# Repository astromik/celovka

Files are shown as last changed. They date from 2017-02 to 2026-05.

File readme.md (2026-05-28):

# Astronomická èelovka s ATtiny25

Praktická èelovka urèená pøedevším pro astronomické pozorování. Obsahuje dvì sady LED (èervenou a bílou) s plynule nastavitelnou intenzitou a extrémnì nízkou spotøebou v režimu spánku.

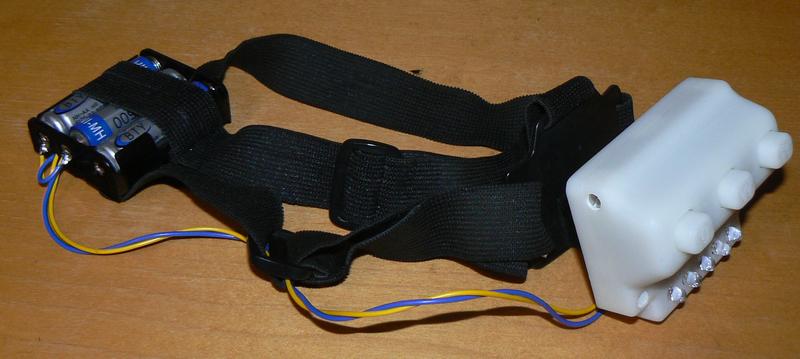
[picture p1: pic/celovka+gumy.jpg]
obrazek celovky vcetne baterii a gum


## Hlavní funkce

- Dvì barvy svìtla (èervená + bílá) s 10 úrovnìmi jasu (logaritmická regulace)
- Režim SLEEP s odbìrem pod 1 µA
- Automatické uspání po 10 minutách neaktivity
- Indikace stavu baterie (1–4 bliknutí)
- Kompaktní a spolehlivé ovládání tøemi tlaèítky

## Ovládání

### Tlaèítko 1 – RED
- **Krátký stisk** (pøi zhasnuto): rozsvítí èervenou sadu LED
- **Krátký stisk** (pøi svícení èervené): zhasne èervenou sadu
- **Dlouhý stisk** (> 1 s): rozsvítí èervenou, ale po uvolnìní tlaèítka se automaticky zhasne
- V režimu nastavení jasu: **zvyšuje jas**

### Tlaèítko 2 – WHITE
- **Dlouhý stisk** (~0,7 s): rozsvítí bílou sadu LED (ochrana proti náhodnému zapnutí)
- Pokud bílá sada LED svítí, stisk tlaèítka WHITE ji zhasne
- V režimu nastavení jasu: **snižuje jas**

### Tlaèítko 3 – OFF
- **Krátký stisk**: zhasne právì svítící LED
- **Držení + RED nebo WHITE** (pøi svícení): vstup do režimu nastavení jasu
- **Dlouhý stisk** (2 s) pøi zhasnutých LED: pøechod do režimu **SLEEP** (nebo probuzení)

### Nastavení jasu
1. Rozsvi�te požadovanou sadu LED
2. Stisknìte a držte tlaèítko **OFF**
3. Tlaèítkem **RED** zvyšujete jas, tlaèítkem **WHITE** snižujete jas (10 krokù)
4. Uvolnìním tlaèítka **OFF** nastavení ukonèíte (LED zùstane svítit)

### Režim SLEEP
- Pøi zhasnutých LED stisknìte tlaèítko **OFF** na ~2 sekundy › 2× blikne èervená LED
- Tlaèítka RED a WHITE se zablokují
- Odbìr klesne **pod 1 µA**

**Probuzení:** Podržte tlaèítko **OFF** na ~2 sekundy › 1× blikne èervená LED.

### Autosleep
Pokud je èelovka déle než ~10 minut neaktivní (LED zhasnuté), automaticky pøejde do režimu SLEEP.

### Test stavu baterie
Pøi zhasnutých LED stisknìte nejprve tlaèítko **WHITE** a do 0,7 sekundy k nìmu pøidejte tlaèítko **RED**.

- Èelovka zaène blikat poslednì použitou barvou
- Poèet bliknutí udává stav baterie:
  - **4×** = baterie dobrá / plná
  - **3×** = stav OK
  - **2×** = baterie slabá
  - **1×** = baterie vybitá (doporuèuji vymìnit)
- Blikání ukonèíte stiskem tlaèítka **OFF**

## Technické informace

**Procesor:** ATtiny25 (8 MHz)  
**Napájení:** 3× AA (1,5V alkalické nebo 1,2V NiMH)  
**Low Fuse:** `0xE2`  
**High Fuse:** `0xD7`  
**Velikost programu:** ~1868 bajtù (91 % FLASH)

**Spotøeba:**
- Zhasnuto (aktivní režim): 4–7 mA
- SLEEP režim: < 1 µA

## Schéma zapojení

*[schéma](https://github.com/astromik/celovka/blob/master/schema/celovka-schema.gif)*

## Kompilace a nahrání

Použijte Arduino IDE + podporu pro ATtiny.  
Doporuèené nastavení:
- Board: ATtiny25/45/85
- Clock: 8 MHz (internal)
- Burn Bootloader (pro správné nastavení fuse bitù)

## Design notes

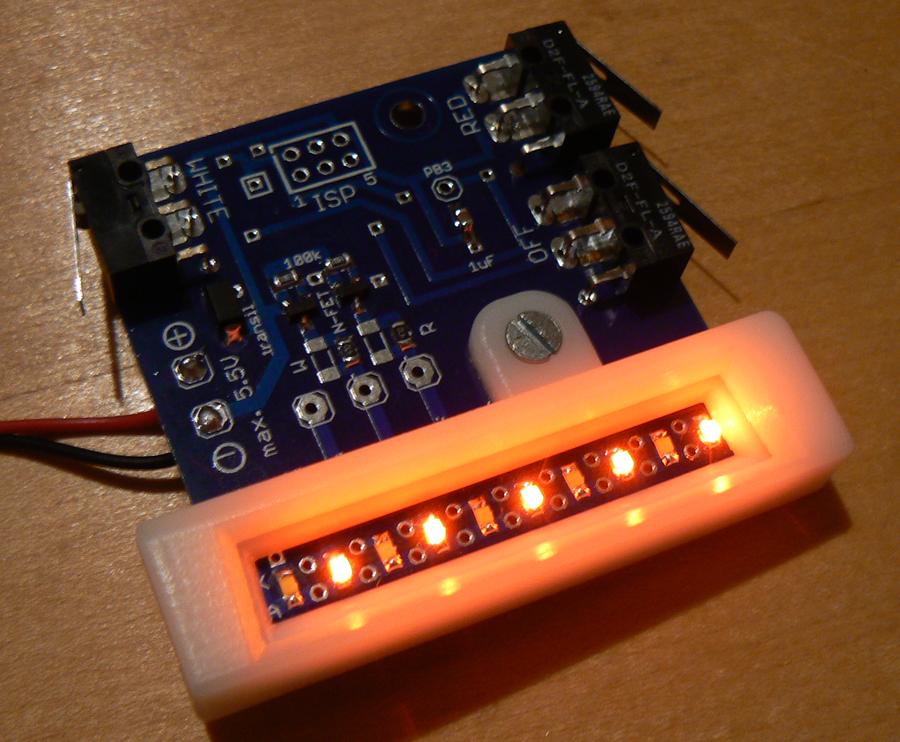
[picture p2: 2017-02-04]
pic/ledshield+pcb1.jpg

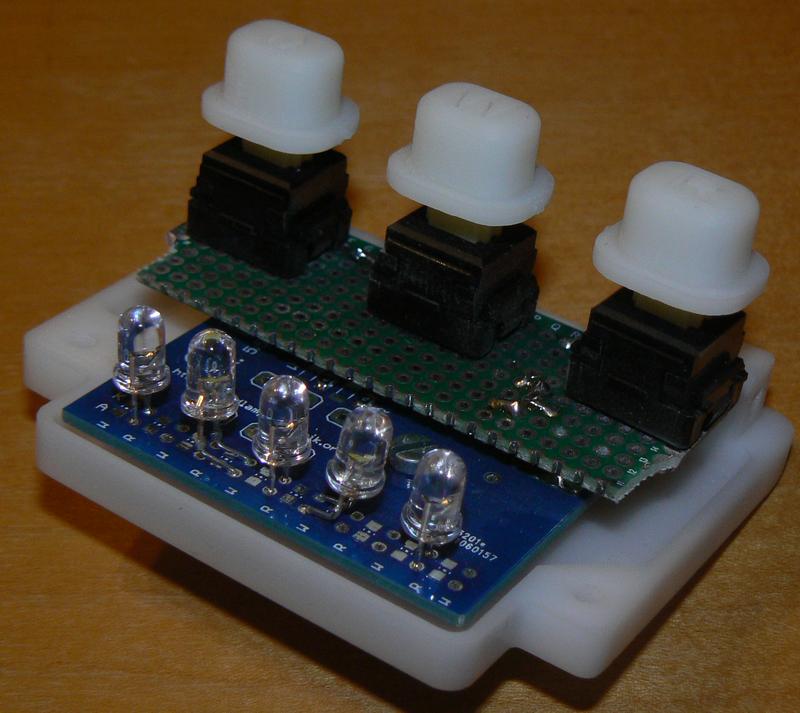
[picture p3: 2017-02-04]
pic/hmatniky.jpg

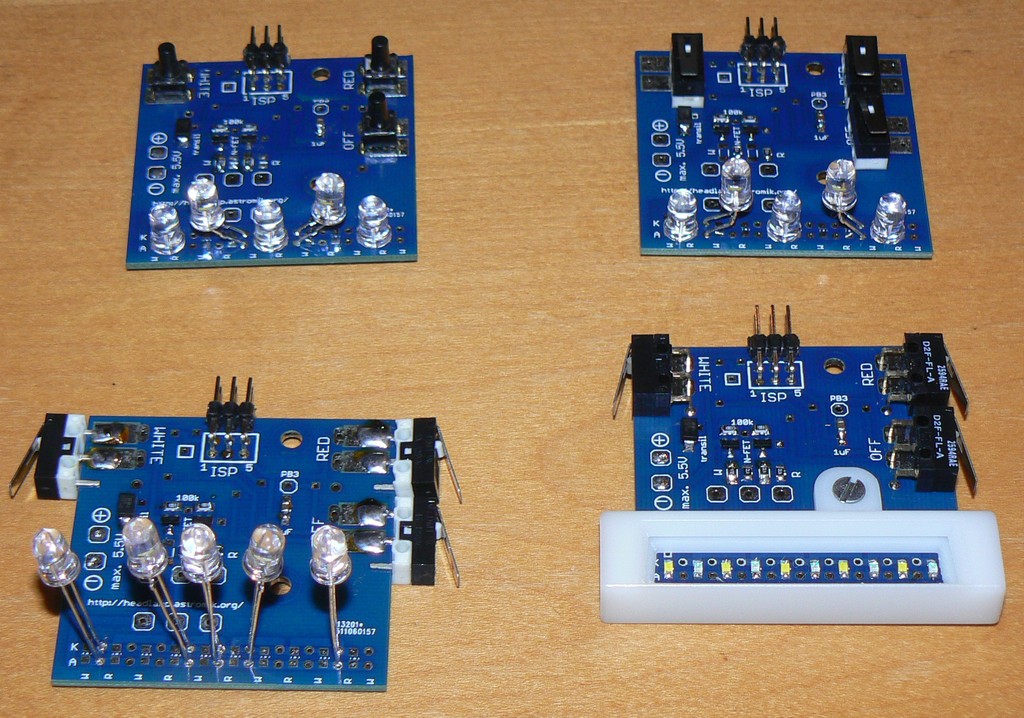
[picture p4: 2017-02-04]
pic/fotka1.jpg

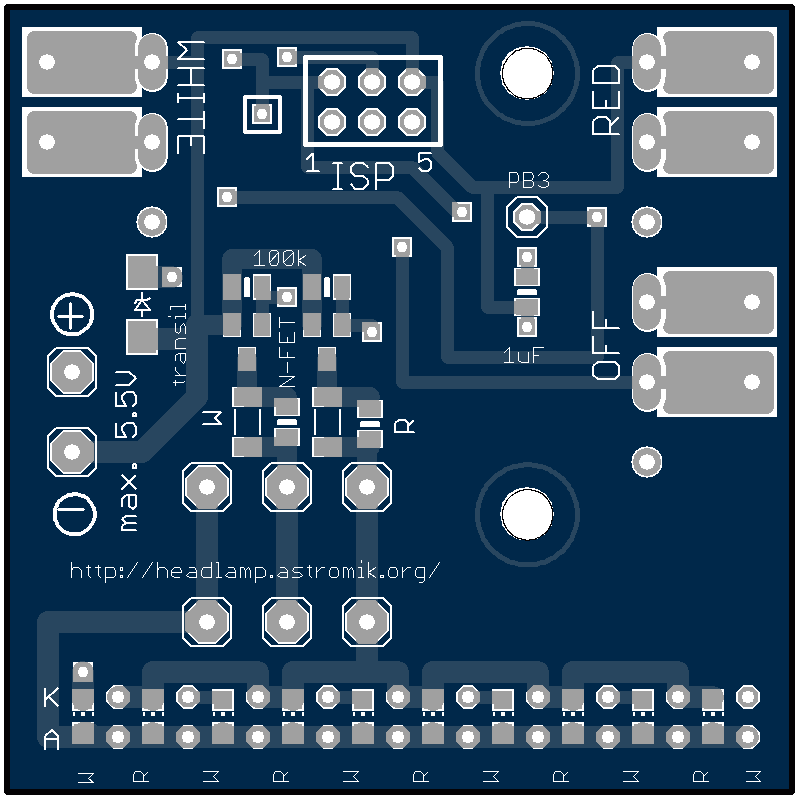
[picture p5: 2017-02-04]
pcb/pcb_top.png

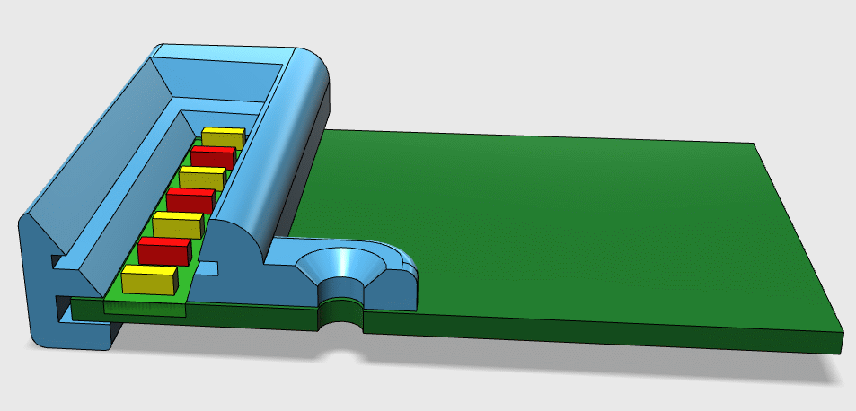
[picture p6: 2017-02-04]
krabicka-3d/ledshield-3d-b.gif

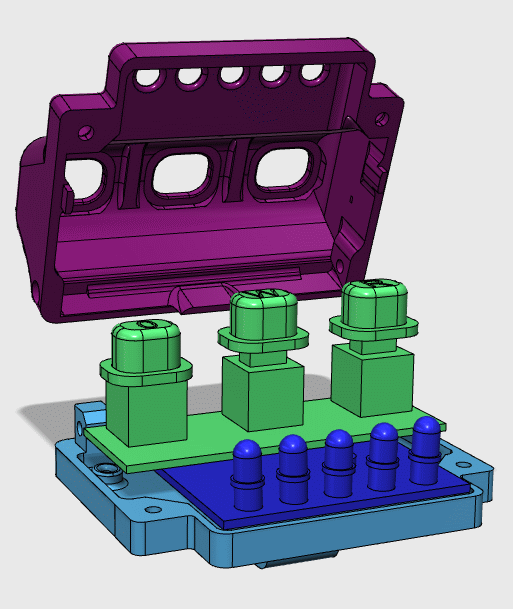
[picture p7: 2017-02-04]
krabicka-3d/krab6-c.gif

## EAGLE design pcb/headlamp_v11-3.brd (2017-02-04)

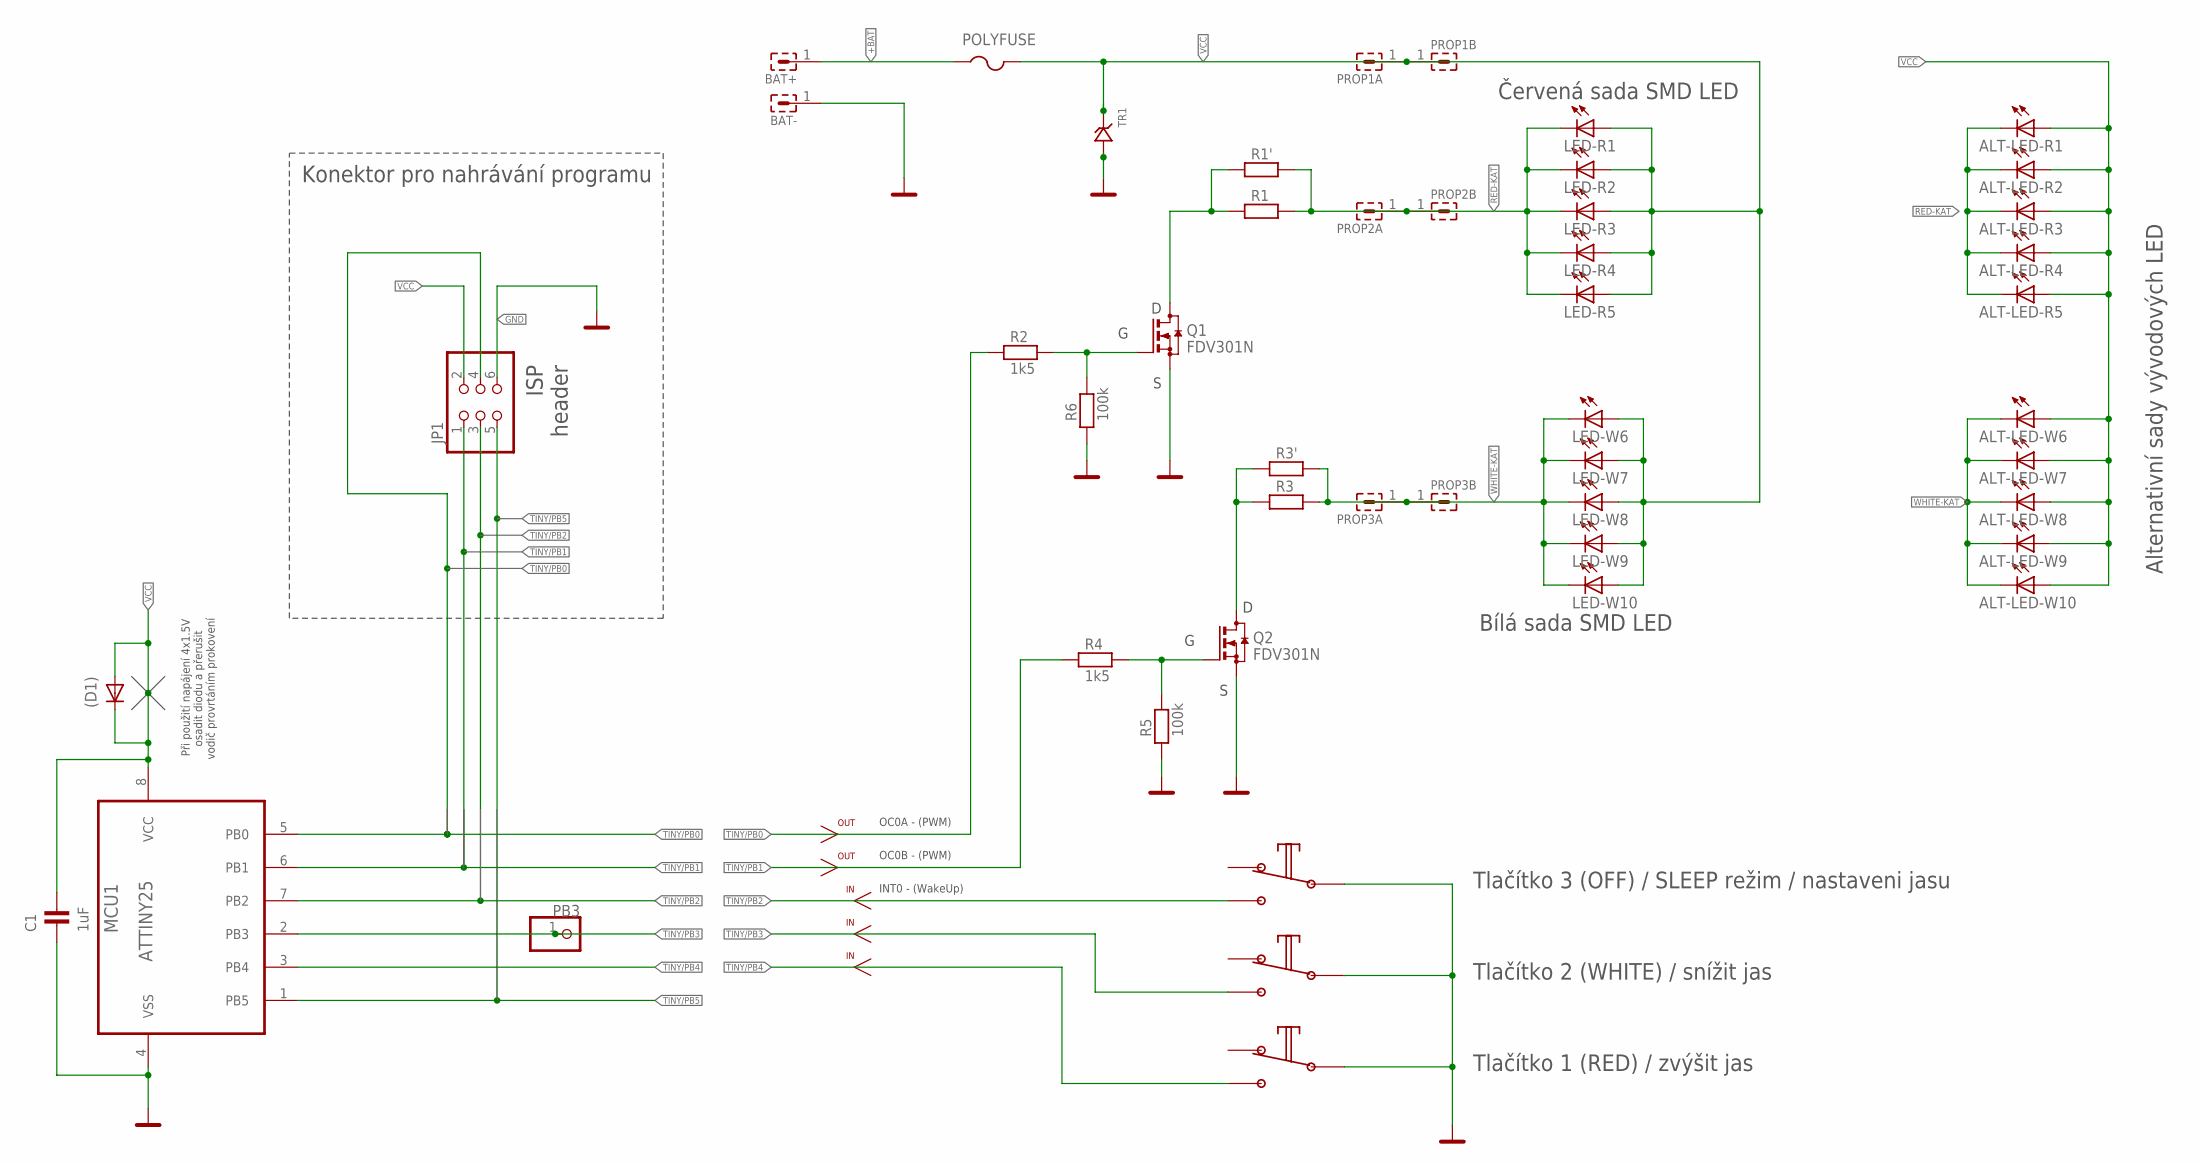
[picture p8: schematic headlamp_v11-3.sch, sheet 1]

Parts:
(D1): DIODE-MINIMELF; MINIMELF
ALT-LED-R1, ALT-LED-R2, ALT-LED-R3, ALT-LED-R4, ALT-LED-R5: LED3MM
ALT-LED-W6, ALT-LED-W7, ALT-LED-W8, ALT-LED-W9, ALT-LED-W10: LED3MM
BAT+: S1G1_JUMP; S1G1_JUM
BAT-: S1G1_JUMP; S1G1_JUM
C1: 1uF; 0805
JP1: PINHD-2X3/90; 2X03/90
LED-R1, LED-R2, LED-R3, LED-R4, LED-R5: LEDCHIP-LED0805; CHIP-LED0805
LED-W6, LED-W7, LED-W8, LED-W9, LED-W10: LEDCHIP-LED0805; CHIP-LED0805
MCU1: ATTINY25; SOIC127P600X175-8N
PB3: PINHD-1X1; 1X01
POLYFUSE: PTCFUSE-1812; 1812
PROP1A, PROP1B, PROP2A, PROP2B, PROP3A, PROP3B: S1G1_JUMP; S1G1_JUM
Q1, Q2: FDV301N; SOT23
R1, R3: R_1206; 1206
R1', R3': R_SMD_0805; 0805
R2, R4: 1k5; 0805
R5, R6: 100k; 0805
TLAC1, TLAC2, TLAC3: TLACITKO
TR1: Transil 6V; DO214AC+MINIMELF_BIDIR

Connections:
+BAT: BAT+.1, POLYFUSE.1
GND: BAT-.1, C1.2, JP1.6, MCU1.4 (VSS), Q1.2 (S), Q2.2 (S), R5.1, R6.1, TLAC1.P$1 (COM), TLAC2.P$1 (COM), TLAC3.P$1 (COM), TR1.P$2
RED-DRAIN: Q1.3 (D), R1.1, R1'.2
RED-KAT: ALT-LED-R1.K (C), ALT-LED-R2.K (C), ALT-LED-R3.K (C), ALT-LED-R4.K (C), ALT-LED-R5.K (C), LED-R1.C, LED-R2.C, LED-R3.C, LED-R4.C, LED-R5.C, PROP2A.1, PROP2B.1, R1.2, R1'.1
RED/GATE: Q1.1 (G), R2.2, R6.2
TINY/PB0: JP1.4, MCU1.5 (PB0), R2.1
TINY/PB1: JP1.1, MCU1.6 (PB1), R4.1
TINY/PB2: JP1.3, MCU1.7 (PB2), TLAC3.P$2 (NO)
TINY/PB3: MCU1.2 (PB3), PB3.1, TLAC2.P$2 (NO)
TINY/PB4: MCU1.3 (PB4), TLAC1.P$2 (NO)
TINY/PB5: JP1.5, MCU1.1 (PB5)
VCC: (D1).A, (D1).C, ALT-LED-R1.A, ALT-LED-R2.A, ALT-LED-R3.A, ALT-LED-R4.A, ALT-LED-R5.A, ALT-LED-W6.A, ALT-LED-W7.A, ALT-LED-W8.A, ALT-LED-W9.A, ALT-LED-W10.A, C1.1, JP1.2, LED-R1.A, LED-R2.A, LED-R3.A, LED-R4.A, LED-R5.A, LED-W6.A, LED-W7.A, LED-W8.A, LED-W9.A, LED-W10.A, MCU1.8 (VCC), POLYFUSE.2, PROP1A.1, PROP1B.1, TR1.P$1
WHITE-DRAIN: Q2.3 (D), R3.1, R3'.2
WHITE-KAT: ALT-LED-W6.K (C), ALT-LED-W7.K (C), ALT-LED-W8.K (C), ALT-LED-W9.K (C), ALT-LED-W10.K (C), LED-W6.C, LED-W7.C, LED-W8.C, LED-W9.C, LED-W10.C, PROP3A.1, PROP3B.1, R3.2, R3'.1
WHITE/GATE: Q2.1 (G), R4.2, R5.2

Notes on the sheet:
ISP header
Konektor pro nahrávání programu
OUT
Červená sada SMD LED
Bílá sada SMD LED
Tlačítko 1 (RED) / zvýšit jas
Tlačítko 2 (WHITE) / snížit jas
Tlačítko 3 (OFF) / SLEEP režim / nastaveni jasu
INT0 - (WakeUp)
OC0A - (PWM)
OC0B - (PWM)
Alternativní sady vývodových LED
Při použití napájení 4x1.5V osadit diodu a přerušit vodič provrtáním prokovení

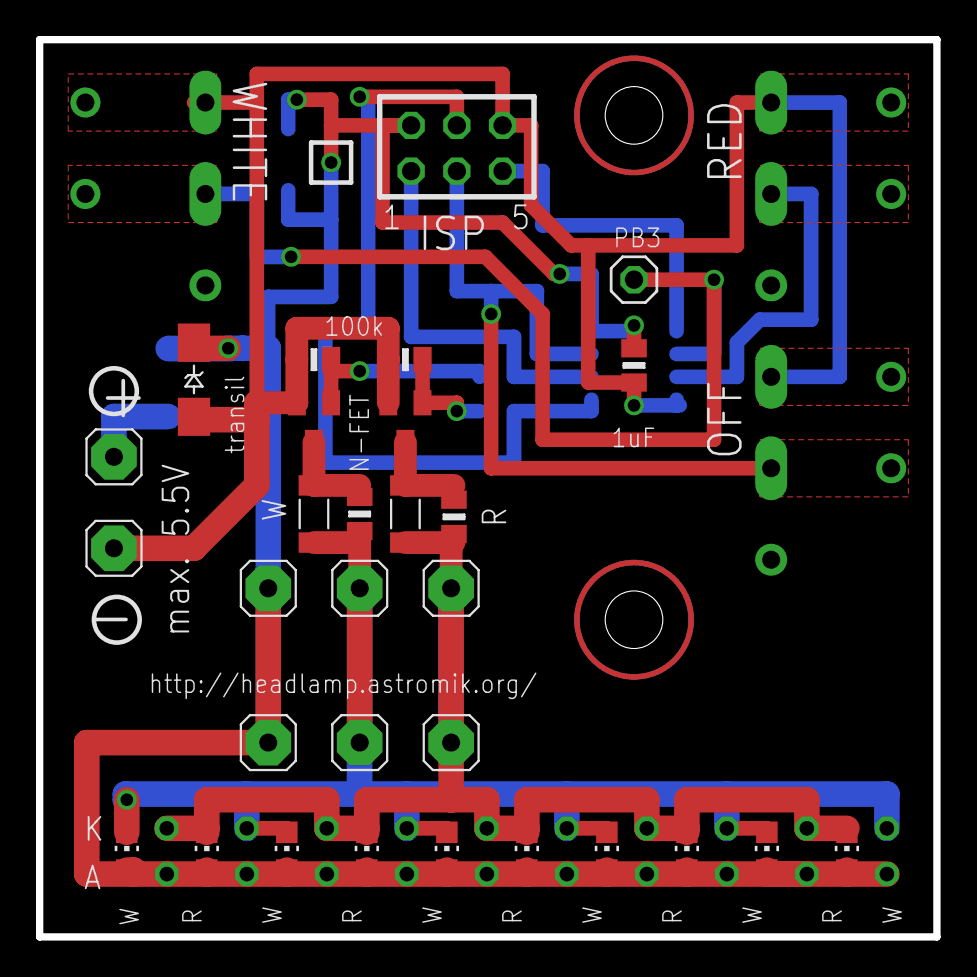
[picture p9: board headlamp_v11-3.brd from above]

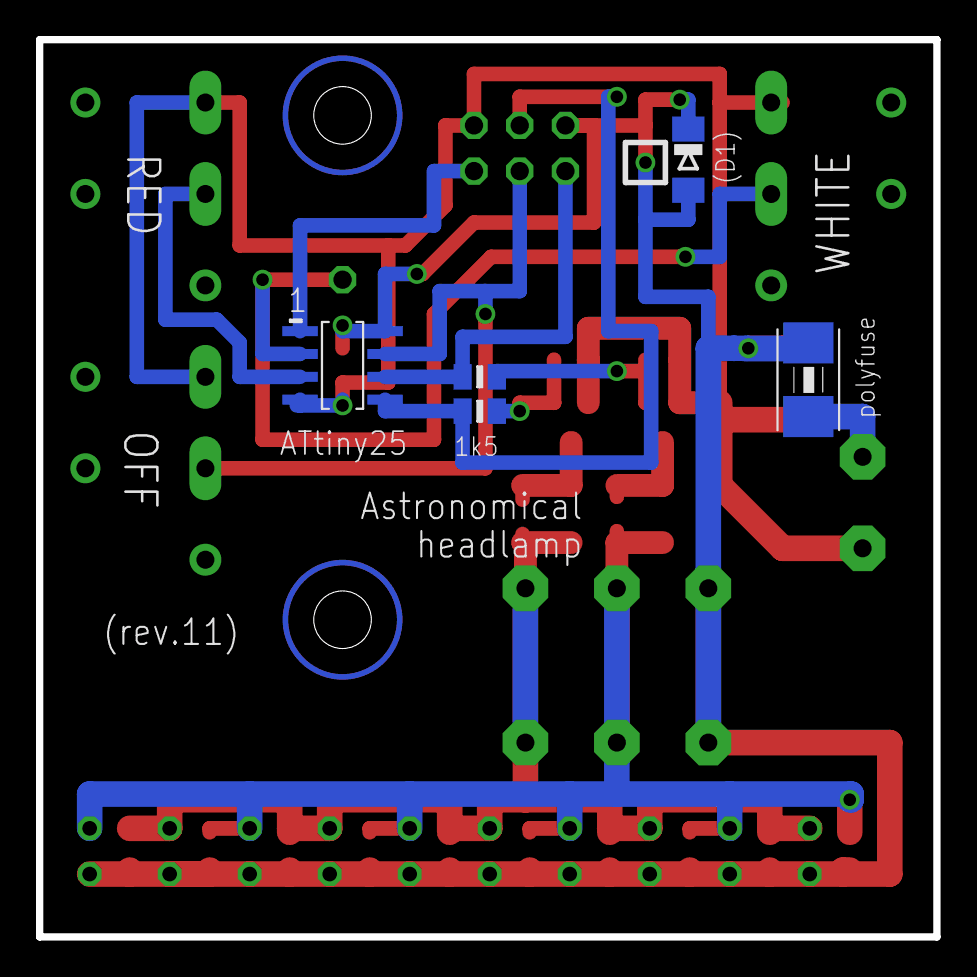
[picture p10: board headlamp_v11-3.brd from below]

Board: 2 copper layers, 49.8 x 49.8 mm, 48 parts (6 on the bottom side), 15 nets.

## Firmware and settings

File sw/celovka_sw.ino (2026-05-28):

//============================================
// Astronomicka celovka s obvodem ATtiny25
//               verze 13
//              (28.5.2026)
//============================================
//   3 tlacitka, prepinani cervenych a bilych LED s nastavitelnou intenzitou obou LED.
//   S moznosti prechodu do rezimu minimalni spotreby.
//
//
//
//  Zapojeni:
//=============
//                                                  ATtiny25
//                                                   +-\_/-+
//              nezapojeno (RESET)           - PB5  1|     |8  Vcc
//          tlacitko [WHITE] ( / snizit jas) - PB3  2|     |7  PB2  - INT0     - tlacitko [OFF] ( / SLEEP / WAKE-UP)
//            tlacitko [RED] ( / zvysit jas) - PB4  3|     |6  PB1  OC0B (PWM) - bila LED - spinana pres FET
//                                             GND  4|     |5  PB0  OC0A (PWM) - cervena LED - spinana pres FET  
//                                                   +-----+
//
//                   (Tlacitka jsou spinana proti GND, LED jsou kvuli vyssim proudum ovladane pres N-FET napr. 2N7000)
//   Napajeni je bud pomoci   3 x 1.2V AA NiMh akumulatory = 3.6 V,
//                            4 x 1.2V AA NiMh akumulatory = 4.8 V,
//                       nebo 3 x 1.5V AA baterie          = 4.5 V
//        v pripade pouziti   4 x 1.5V AA baterie          = 6   V,  je treba snizit napeti do ATtiny pomoci seriove zapojene diody na vyvodu Vcc
//
//
// nastaveni FUSE bajtu:
//========================
// LowFUSE  : 0xE2         8MHz pro zrychleni PWM. Pri nastaveni 1MHz bylo pri pohybu celovky videt neprijemne prerusovane blikani LED.
// HighFUSE : 0xD7
//
// velikost prelozeneho programu 2032 Bajtu (99% obsazene PROGMEM)


// Seznam zmen verze 13 proti verzi 12 (z 2.4.2016):
//---------------------------------
// Funkce BLIKAC byla nahrazena funkci testu stavu baterie
//     Soucasnym stiskem tlacitek [WHITE] + [RED] (nejdriv [WHITE] a behem 0.7 sekundy pridat [RED]) se zacne vyblikavat kod 1 az 4 podle stavu napajeciho napeti (1x = slaba baterie ... 4x = baterie v poradku)
//     Barva a jas blikani jsou stejne, jako bylo posledni pouzite sviceni.
//     Ukonceni blikani stiskem tlacitka [OFF]. Sice se ted neda volit rezim blikani, ale alespon omezene blikani bylo zachovano.
// Doplnena moznost jednoduchou upravou kodu prohodit pripojeni tlacitek [RED] a [WHITE]
// Svitici bilou sadu LED je mozne zhasnout stiskem tlacitka [WHITE]. Drive tlacitko [WHITE] pri sviticich bilych LED nic nedelalo a bila se musela hlasnout pomoci [OFF], nebo prepnutim na [RED]
// Tajna funkce:
//     Pokud se pri resetu (pri vkladani baterii) budou drzet vsechna 3 tlacitka stisknuta, nebude se bila sada LED rozsvecovat skokove, ale narust jasu bude pozvolny.
//     Prechod z nuloveho na maximalni jas trva asi 2 sekundy. 
//     Je to jen takova "dyzajnovka", postupne rozsveceni je trochu prijemnejsi na oci.
//     Nevyhoda je pomalejsi reakce. Zhasnuti bile sady LED tlacitkem [WHITE] je mozne az po jejich uplnem rozsviceni.
//     Vraceni puvodni funkce skokoveho rozsvecovani bile sady LED je mozne dalsim resetem (vlozenim baterii) bez stisknutych tlacitek.
//     Nastaveny zpusob rozsveceni bile sady LED si procesor pamatuje i v rezimu spanku.



// Seznam zmen verze 12 proti verzi 11 (z 10.11.2015):
//---------------------------------
//  Tlacitko [RED] ma dve nove funkce:
//       1) pri rozsvicene cervene LED je mozne tuto LED stejnym tlacitkem zase zhasnout - neni tedy treba prehmatavat na tlacitko [OFF]
//       2) pri stisku tohoto tlacitka na dele nez 1 sekundu se pri jeho uvolneni cervena LED automaticky zhasne - tlacitko funguje jako normalni tlacitko
//  Kvuli velikosti programu bylo nutne ve funkci BLIKAC ubrat nejpomalejsi rezim blikani (1 sekunda svetlo, 15 sekund tma)





//=============================================================================================================

#include <avr/interrupt.h>
#include <avr/sleep.h>
#include <stdint.h>

#define tlacitko_RED          0b00010000                         // PB4 tlacitka [RED] a [WHITE] je mozne navzajem prohodit
#define tlacitko_WHITE        0b00001000                         // PB3



#define tlacitko_OFF           0b00000100                         // PB2 kvuli probouzeni pres pevy signal INT0 nelze pozici tlacitka menit

#define STISKNUTO(x)          (!(PINB & (x)))                     // stisknute tlacitko je spojene na GND, takze vraci LOW
#define UVOLNENO(x)             (PINB & (x))                      // uvolnene tlacitko je pull-upovane, takze vraci HIGH


// casovaci konstanty v [ms] (kvuli zmene frekvence procesoru na 8MHz je nutne pozadovany cas nasobit 8x)
#define timer_30             8 *   30                             // 30ms pauza pro osetreni zakmitu tlacitek a pro casovanio pruchdu hlavni smyckou
#define bat_led_on           8 *  125                             // pri vyblikavani kodu pro stav baterie urcuje dobu trvani rozsvicene LED
#define bat_led_off          8 *  250                             // pri vyblikavani kodu pro stav baterie urcuje dobu trvani zhasnute LED
#define bat_led_mezera       8 * 1250                             // pri vyblikavani kodu pro stav baterie urcuje dobu mezi opakovanim sekvence bliknuti
#define blikred_led_on       8 *  200                             // delka trvani rozsvicene LED pri signalizaci rucniho uspani nebo probuzeni procesoru
#define blikred_led_off      8 *  200                             // delka trvani zhasnute LED pri signalizaci rucniho uspani nebo probuzeni procesoru
#define longpress_white      8 *  700                             // doba trvani drzeni tlacitka [WHITE] pred skutecnym rozsvicenim bile sady LED
#define change_level_timer   8 *  500                             // pauza mezi zmenami jasu LED v rezimu nastaveni jasu
#define wakeup_timer         8 *  100                             // pauza na zotaveni po probuzeni z rezimu spanku
#define longpress_red        8 * 1000                             // doba trvani drzeni tlacitka [RED] po kterem se tlacitko chova jako tlacitko a po uvolneni LED hned zhasne
#define longpress_off        8 * 2000                             // doba drzeni tlacitka [OFF] nutna k probuzeni nebo uspani procesoru

#define boot_timer           1000                                 // cas necinnosti [ms] pri startu napajeni - osetreni zakmitu pri vkladani baterii do drzaku

#define cykly_autosleep   20000;                                  // pauza v cyklech pred prechodem do automatickeho uspani. Jeden cyklus trva asi 30ms (konstanta "timer_30").
                                                                  // 20000 cyklu odpovida asi 10 minutam


volatile uint8_t level_red = 4;                                   // uroven jasu cervene LED - po zapnuti napajeni se cervena LED nastavi na 50%  (urovne jsou 0 az 9 pro 10% az 100% jasu)
volatile uint8_t level_white = 7;                                 // uroven jasu bile LED - po zapnuti napajeni se bila LED nastavi na 80%  (urovne jsou 0 az 9 pro 10% az 100% jasu)
volatile uint8_t prave_sviti = 0;                                 // pomocna promenna pro indikaci prave svitici LED (0= nesviti zadna; 1= sviti cervena; 2= sviti bila)
volatile uint8_t byla_zmena;                                      // pomocna promenna pro rozliseni, jsetli je uvolneni tlacitka [OFF] navratem z nastaveni, nebo obycejnym zhasnutim
volatile uint8_t zamek = 0;                                       // informace o tom, jestli ma pokracovat SLEEP rezim po nahodnem kratkem stisku tlacitka [OFF], nebo jestli se ma SLEEP ukoncit po dlouhem stisku       
volatile uint32_t autosleep;                                      // automaticky prechod do rezimu SLEEP po 10 minutach, kdy jsou obe LED zhasnute (hodnota casu se nastavuje v podprogramu "obe_off()" )
volatile uint32_t starttime;                                      // pomocna promenna pro zjistovani delky sepnuti tlacitka
volatile uint8_t posledni_barva = 1;                              // promenna pro zapamatovani posledni pouzite barvy LED - kvuli funkci blikace, kdy pak bude blikat stejna LED (1=cervena , 2= bila)

bool slow_white = false;                                          // pomaly nabeh bile sady LED je mozne zapnout pri resetu (pri vkladani baterii) drzenim vsech 3 tlacitek. Defaultne je pomaly nabeh vypnuty.

// ===================================================================
// zmena jasu LED neni provadena linearne, ale logaritmicky.
//    (protoze je dobre znatelny rozdil v jasu mezi cisly 253 a 254, ale neni pozorovatelny zadny rozdil v jasech mezi cisly 10 a 11 )
const byte logaritmy[] = {254,253,252,249,243,233,215,181,117,0}; // 0 = maximalni jas LED ; 255 = zhasnute LED



// ===================================================================
// temhle podprogram je tu jen kvuli uspore mista ve FLASH pameti ATtiny25
// volanim podprogramu "pauza_30()" se proti volani funkce "delay(30)" usetri v tomto programu vice nez 100 bajtu pameti
void pauza_30(void)
  {
    delay(timer_30);
  }



// ===================================================================
// Mereni napeti baterie pres interni bandgap referenci (1.1V)
uint8_t getBatteryLevel(void)
{
  ADMUX = (0 << REFS0) | (1 << MUX3) | (1 << MUX2);               // 1.1V bandgap vs Vcc
  delay(16);                                                      // povinna pauza 2ms * 8
  ADCSRA |= (1 << ADSC);
  while (bit_is_set(ADCSRA, ADSC));

  uint16_t adc = ADC;
                                                                  // procesor funguje i pri napeti pod 2V, ale nektere typy LED uz se nedokazi na takto malem napeti rozsvitit
                                                                  // Velikost napeti ovlivnuje i svitivost LED, takze pri nizsim napajeni je nutne zvysit stupen jasu.

                                                                  // pokusne zjistene hodnoty napeti pro ruzne 'adc' meze.
                                                                  // Navratova hodnota udava pocet bliknuti pri funkci testovani baterie.
  if (adc > 390) return 1;                                        // napeti velmi spatne  ( pod 2.9V)
  if (adc > 340) return 2;                                        // napeti slabe         ( 2.9V az 3.2V)
  if (adc > 280) return 3;                                        // napeti stredni       ( 3.3V az 3.9V)
  return 4;                                                       // napeti v poradku     ( nad 3.9V)
}

// ===================================================================
// rozsviceni cervene LED (PWM kanal A - pin PB0)
// parametrem je index pole logaritmy[]  ; 0 az 9 odpovida 10% az 100% jasu
void red_on(byte level_red)
  {
    OCR0A  = logaritmy[level_red];                                // sirka PWM impulzu
    prave_sviti = 1;                                              // prave sviti cervena LED
  }


// ===================================================================
// rozsviceni bile LED (PWM kanal B - pin PB1)
// parametrem je index pole logaritmy[]  ; 0 az 9 odpovida 10% az 100% jasu
void white_on(byte WHITE)
  {
    OCR0B  = logaritmy[WHITE];                                    // sirka PWM impulzu
    prave_sviti = 2;                                              // prave sviti bila LED
  }

// ===================================================================
// bez parametru se postupne rozsviti bila sada LED (PWM kanal B - pin PB1) na posledni nastaveny jas bile LED
void white_on(void)
  {
    byte zkratka = 0;
    for (byte i = 255 ; i > logaritmy[level_white] ; i--)         // zacina se od nizkeho jasu a postupne se zjasnuje
      {
        OCR0B = i;
        if (i > 150)                                              // dynamicka pauza se dela jen pro nizke jasy 
          {
            zkratka = inter_pauza(i,false);                       // pri parametru 0 se budou testovat obe tlacitka [RED] i [OFF]
            if (zkratka > 0 )                                     // kdyz se behem rozsveceni stiskne [OFF] nebo [RED]
              {
                break;
              }
          }
      }
    
    if (zkratka < 2)                                              // pri zkraceni smycky pomoci tlacitka [OFF] (zkratka=1), nebo pri dokonceni pozvolneho dobehu (zkratka=0) 
      {
        OCR0B = logaritmy[level_white];                           // dojde k okamzitemu rozsviceni na nastavenou uroven (preskoci se pozvolny najezd) - je mozne hned nastavovat jas bile LED
        prave_sviti = 2;                                          // prave sviti bila LED
      }
    if (zkratka == 2)                                             // pri zkraceni smycky pomoci tlacitka [RED]
      {
        obe_off();                                                // se bila zhasne a v pristim kroku se hned rozsviti cervena sada LED, protoze je stisknute cervene tlacitko
      }
          
  }



// ===================================================================
// zhasne obe LED
void obe_off(void)
  {
     OCR0A  = 255;                                                // PWM na cervene LED na sirku impulzu 0% (zhasne cervenou LED)
     OCR0B  = 255;                                                // PWM na bile LED na sirku impulzu 0% (zhasne bilou LED)
     prave_sviti = 0;                                             // prave nesviti zadna LED
     autosleep = cykly_autosleep;                                 // pri zhasnuti obou LED se nastavi odpocet automatickeho uspani asi na 10 minut     
  }
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
void loop()
  {

    // ===================================================================
    // stisk tlacitka [RED] - obycejne, okamzite rozsviceni cervene LED

    // kdyz nesviti cervena LED a je sepnute pouze tlacitko [RED]
    if (prave_sviti != 1 && STISKNUTO(tlacitko_RED) && UVOLNENO(tlacitko_WHITE) && UVOLNENO(tlacitko_OFF)) 
      {
        obe_off();                                                // Obe LED zhasnout
        red_on(level_red);                                        // Rozsvit cervenou LED pozadovanym jasem
        posledni_barva = 1;                                       // pamet posledni svitici barvy LED - kvuli funkci BLIKAC v testu stavu baterie 

        starttime = millis();                                     // zapamatovani casu rozsviceni kvuli funkci automatickeho zhasnuti pri delsim drzeni cerveneho tlacitka
        pauza_30();                                               // odruseni zakmitu tlacitka [RED]
        while (STISKNUTO(tlacitko_RED))                           // cekani na uvolneni cerveneho tlacitka
          {
            pauza_30();
          }      
        if (millis() > starttime + longpress_red)                 // pokud bylo cervene tlacitko stisknute na delsi dobu, nez 1 sekunda, ...
          {
            obe_off();                                            //  ... tak se po uvolneni cervena LED zase zhasne
          }
      }



    // ===================================================================
    // stisk tlacitka [RED] pri rozsvicene cervene LED, cervenou LED zhasina
    // kdyz cervena LED sviti a je sepnute pouze tlacitko [RED]
    if (prave_sviti == 1 &&  STISKNUTO(tlacitko_RED) && UVOLNENO(tlacitko_WHITE) && UVOLNENO(tlacitko_OFF))
      {
        obe_off();                                                // cervenou LED zhasnout
        pauza_30();                                               // odruseni zakmitu tlacitka [RED]
        while (STISKNUTO(tlacitko_RED))                           // cekani na uvolneni cerveneho tlacitka
          {}
        pauza_30();                                               // odruseni zakmitu tlacitka [RED]
      }



    // ===================================================================
    // stisk tlacitka [WHITE] - obycejne rozsviceni bile LED (casovane - rozsviti se az po 0.7 sek drzeni tlacitka [WHITE])

    // kdyz nesviti bila LED a je sepnute pouze tlacitko [WHITE]
    if (prave_sviti != 2 && (STISKNUTO(tlacitko_WHITE)) && UVOLNENO(tlacitko_RED) && UVOLNENO(tlacitko_OFF))
      {
        pauza_30();                                               // odruseni zakmitu tlacitka [WHITE]

        starttime = millis();                                     // cas zacatku stisku tlacitka [WHITE] do promenne
        while (STISKNUTO(tlacitko_WHITE))                         // dokud je sepnute tlacitko [WHITE]
          {
            if (millis() > (starttime + (longpress_white)))       // kdyz je tlacitko [WHITE] stisknuto asi 0.7 sekundy ...
              {

                 // kdyz je po te 0.7 sekunde stisknute spolecne s tlacitkem [WHITE] i tlacitko [RED] (tlacitko [OFF] je uvolnene)
                 if (STISKNUTO(tlacitko_WHITE) && STISKNUTO(tlacitko_RED) && UVOLNENO(tlacitko_OFF))
                   {
                     test_napeti();                               // ... prejde se do rezimu testovani napajeciho napeti
                   }
                 else                                             // kdyz po 0.7 sekunde neni stisknute tlacitko [RED], znamena to obycejne rozsviceni bile LED
                   {                    
                     if (prave_sviti != 2)                        // Kdyz bila nesviti, rozsvit ji pozvolna
                       {
                         obe_off();                               // ... obe LED zhasnout
                         if (slow_white == true)  white_on();     // postupne rozsviceni na nastavenou uroven
                         else          white_on(level_white);     // okamzite rozsviceni bez pozvolneho nabehu
                       }
                     posledni_barva = 2;                          // pamet posledni svitici barvy LED - kvuli funkci BLIKAC pri mereni napajeciho napeti

                   }
              }
              pauza_30();
           }
      }

    // ===================================================================
    // stisk tlacitka [WHITE] - pri sviticich bilych LED je zhasne

    // kdyz sviti bila LED a je sepnute pouze tlacitko [WHITE]
    if (prave_sviti == 2 && (STISKNUTO(tlacitko_WHITE)) && UVOLNENO(tlacitko_RED) && UVOLNENO(tlacitko_OFF))
      {
        obe_off();
      }



    // ===================================================================
    // stisk tlacitka [OFF] (pri zmacknutem tlacitku [OFF] je spusten rezim "NASTAVENI JASU")

    // nejaka LED sviti a je stisknuto pouze tlacitko OFF
    if (prave_sviti != 0 && STISKNUTO(tlacitko_OFF) && UVOLNENO(tlacitko_RED) && UVOLNENO(tlacitko_WHITE))
      {
        // vstup do rezimu nastaveni jasu
        pauza_30();                                               // odruseni zakmitu tlacitka [OFF]        
        
        byla_zmena = 0;                                           // pomocna promenna pro zjisteni, jestli po uvolneni tlacitka [OFF] zhasnout (= 0) nebo nechat svitit (= 1) LED

        while (STISKNUTO(tlacitko_OFF))                           // dokud je tlacitko [OFF] sepnute (nezavisle na tom, jak jsou na tom ostatni tlacitka)
          {
             if (STISKNUTO(tlacitko_RED))                         // a zaroven je stisknuto tlacitko [RED] (zvysovani jasu)
               {
                 if (prave_sviti == 1)                            // a kdyz prave sviti cervena
                   {
                     if (level_red == 9) level_red = 8;           // test na prekroceni rozsahu pri zvetsovani jasu (nikdy nebude vic, nez 9)
                     level_red ++;                                // zvetseni cerveneho jasu
                     red_on(level_red);                           // fyzicka aktualizace jasu cervene LED
                     byla_zmena = 1;                              // byla provedena zmena jasu, takze po uvolneni tlacitka [OFF] se nebude cervena LED zhasinat
                   }
                 if (prave_sviti == 2)                            // kdyz prave sviti bila
                   {
                     if (level_white == 9) level_white = 8;       // test na prekroceni rozsahu pri zvetsovani jasu (nikdy nebude vic, nez 9)
                     level_white ++;                              // zvetseni bileho jasu
                     white_on(level_white);                       // fyzicka aktualizace jasu bile LED
                     byla_zmena = 1;                              // byla provedena zmena jasu, takze po uvolneni tlacitka [OFF] se nebude bila LED zhasinat                   
                   }
                 
                 delay(change_level_timer);                       // 0.5s pauza mezi jednotlivymi kroky pri zvysovani jasu
               }
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

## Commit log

2017-02-04 ver. 11
    [headlamp_v11-3.brd, headlamp_v11-3.sch]
2026-05-28 Verze 13
    Verze čelovky s měřením napětí napájecí baterie.
    Byl zrušen výběr typu blikání ve funkci BLIKAČ.
    Při rozsvícené bílé sadě LED je tlačítko WHITE zhasne.
    Zjednodušená možnost prohození tlačítek RED a WHITE úpravou dvou řádek v programu.
    Tajná funkce pro přepnutí na pomalé rozsvěcení bílé sady LED (postup popsán v komentáři uvnitř programu).
2026-05-28 Doplnění nastavení Arduino IDE
    Obrázky s nastavením pro ATtiny25
2026-05-28 Aktualizace obrázků IDE
    Změny v obrázcích nastavení Arduino IDE

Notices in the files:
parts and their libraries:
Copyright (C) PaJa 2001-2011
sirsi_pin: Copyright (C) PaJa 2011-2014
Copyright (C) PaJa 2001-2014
